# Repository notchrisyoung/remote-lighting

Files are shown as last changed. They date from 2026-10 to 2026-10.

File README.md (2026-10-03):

# Remote Lighting

A wireless dimmer system for LED lighting built from Arduinos and **nRF24L01 2.4 GHz radios**. A wall-mounted button **Controller**, built into a standard single-gang switch plate, sends commands to one or more **Receivers**. Each receiver drives up to three dimmable lighting zones with PWM.

Built in **2018** for under-cabinet kitchen lighting (the photos below are from then), and added to GitHub in April 2021.

| | |
|---|---|
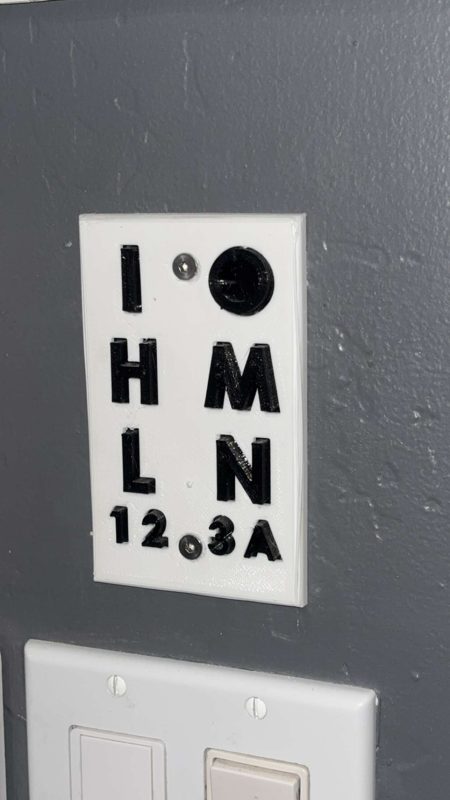
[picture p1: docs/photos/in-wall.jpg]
The in-wall control plate
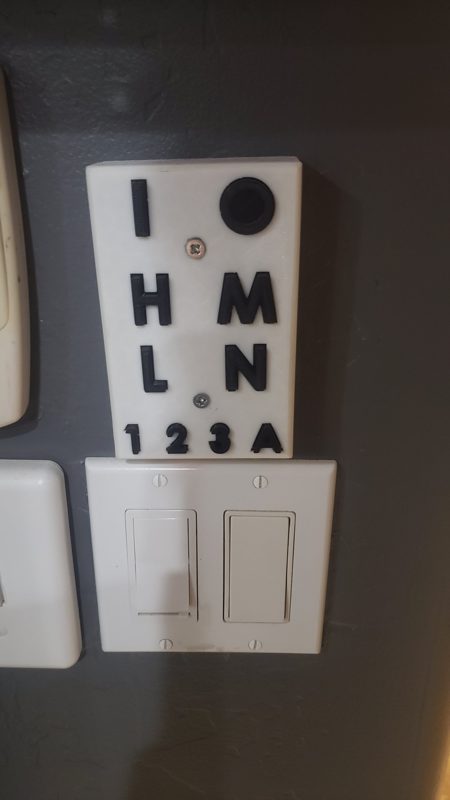
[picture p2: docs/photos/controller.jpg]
The surface-mounted controller
|  |  |
| The in-wall version: the electronics sit inside the wall box, so only the plate shows, like a normal switch plate | The surface-mounted version, with the electronics in a printed box over the wall box |

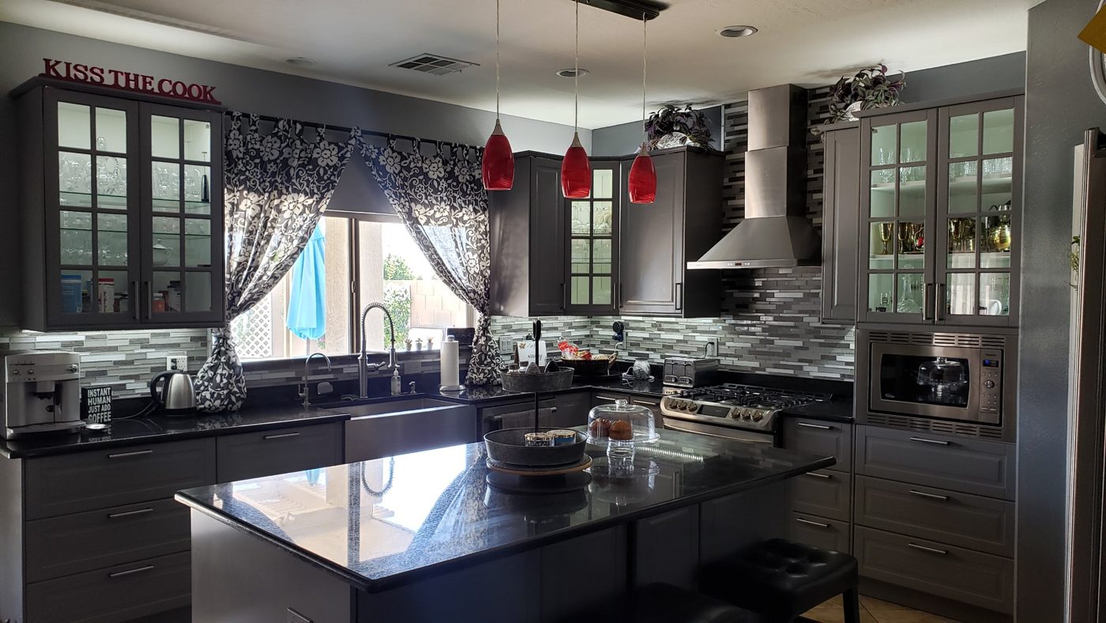
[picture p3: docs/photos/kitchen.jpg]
The kitchen


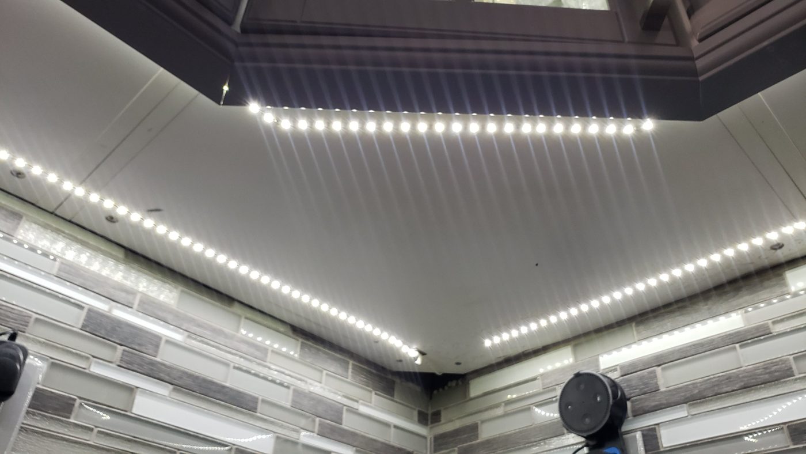
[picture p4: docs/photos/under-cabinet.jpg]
The LED strips under the cabinets


*The kitchen, and the LED strips under the cabinets that the system controls.*

## Features

- **On / Off** for the selected zones. Pressing *On* when already on turns all zones on, and pressing *Off* when already off turns all zones off.
- **Zones 1, 2, 3, or All**
- **Four brightness levels:** High, Medium, Low, and Night light
- Supports up to 4 receivers out of the box (more with a small config change)

## How it works

Every command is a single byte sent over the radio:

| Bits 7-6 | Bit 5 | Bits 4-2 | Bits 1-0 |
|---|---|---|---|
| unused | State: 1 = on, 0 = off | Zone: `001` = 1, `010` = 2, `100` = 3, `111` = all | Brightness: `11` High, `10` Med, `01` Low, `00` Night light |

Receivers map the brightness level to a PWM value (`5, 50, 150, 255`) on each selected zone's pin.

## Hardware

**Controller**
- Arduino (Uno/Nano-class) + nRF24L01 (CE pin 9, CSN pin 10, SPI)
- 10 buttons:

| Button | Pin |
|---|---|
| On | 7 |
| Off | 8 |
| High | A0 |
| Medium | A1 |
| Low | A2 |
| Night light | 6 |
| Zone 1 | 5 |
| Zone 2 | 4 |
| Zone 3 | 3 |
| All zones | 2 |

**Each receiver**
- Arduino + nRF24L01 (CE 9, CSN 10)
- Three MOSFETs on heatsinks driving the LED zones from PWM pins **3, 5 and 6** (zones 1-3)
- 12 V LED strip and a 12 V power supply

## Build

### Controller

| | | |
|---|---|---|
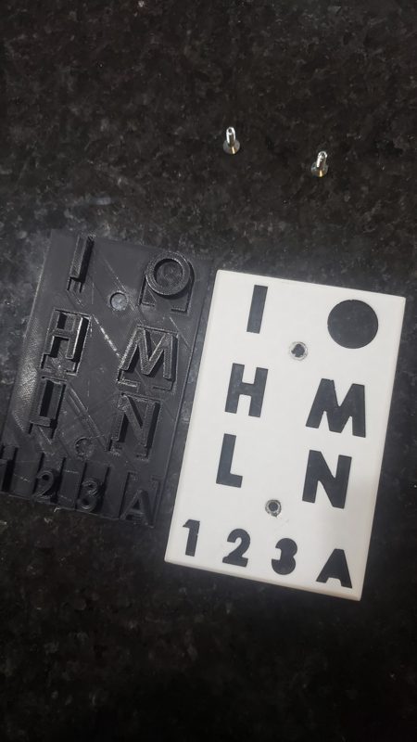
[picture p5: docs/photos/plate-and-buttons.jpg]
Printed wall plate and button sheet
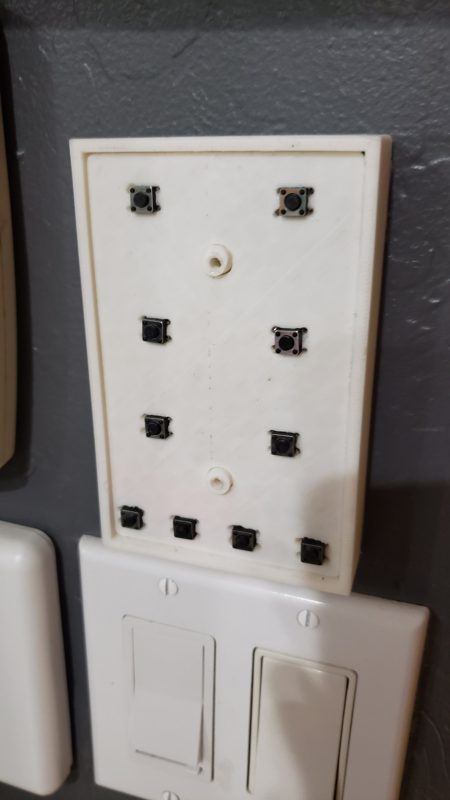
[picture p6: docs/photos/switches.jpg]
The tactile switches under the buttons
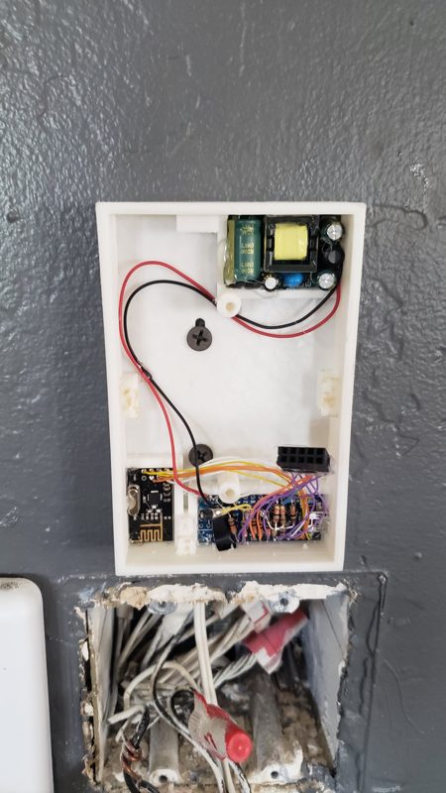
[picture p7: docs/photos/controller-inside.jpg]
Inside the controller
|  |  |  |
| The wall plate and the one-piece letter-button sheet that sits behind it | With the plate off: the 10 tactile switches the letters press | Inside: a small mains-to-DC power module (top), the nRF24L01 radio and the Arduino (bottom) |

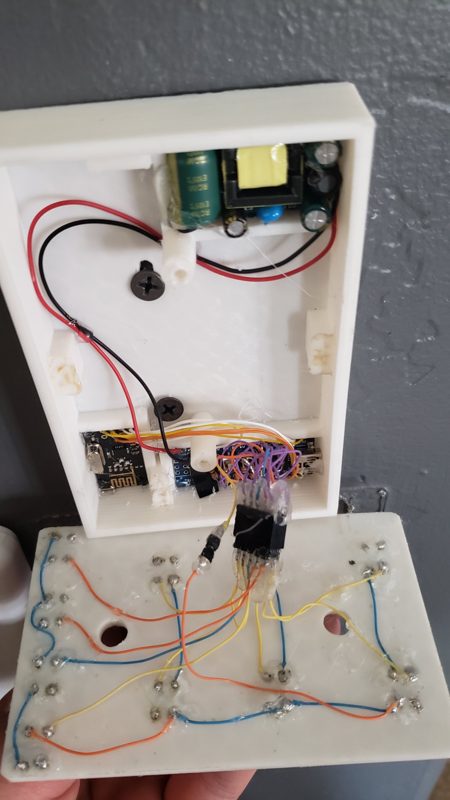
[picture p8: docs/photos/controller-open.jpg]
The controller opened up


The switches are mounted on a printed board and hand-wired to a header that plugs into the Arduino. Behind the controller there's a standard electrical box in the wall, the same kind a normal light switch sits in. The controller mounts over it like a switch plate would, and the box brings mains power to the power module.

> **Mains voltage:** the controller's power module is wired to household mains. Turn the breaker off before working on it, and if you aren't comfortable with mains wiring, power the controller from a USB supply instead.

### Receiver

| | | |
|---|---|---|
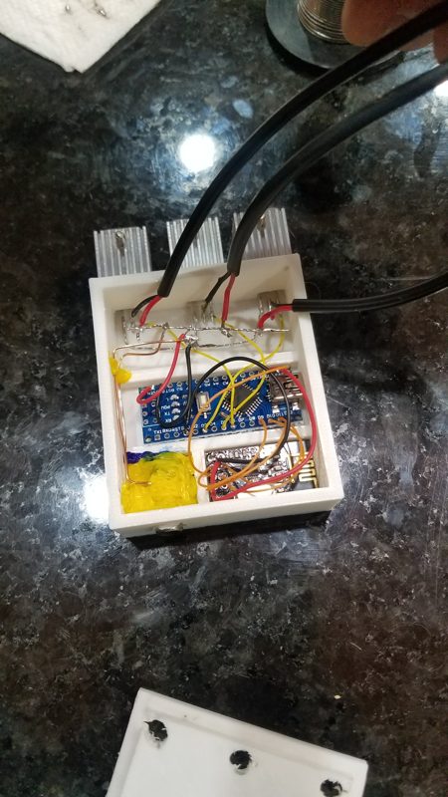
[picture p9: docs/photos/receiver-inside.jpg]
Inside a receiver
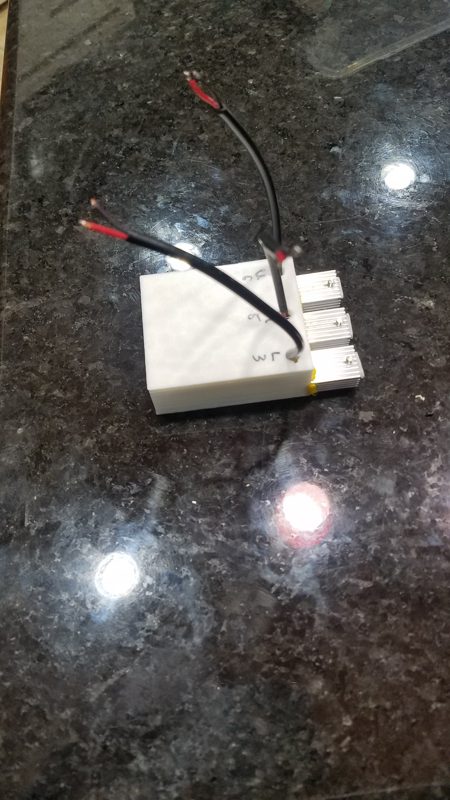
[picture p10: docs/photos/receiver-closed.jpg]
A closed receiver
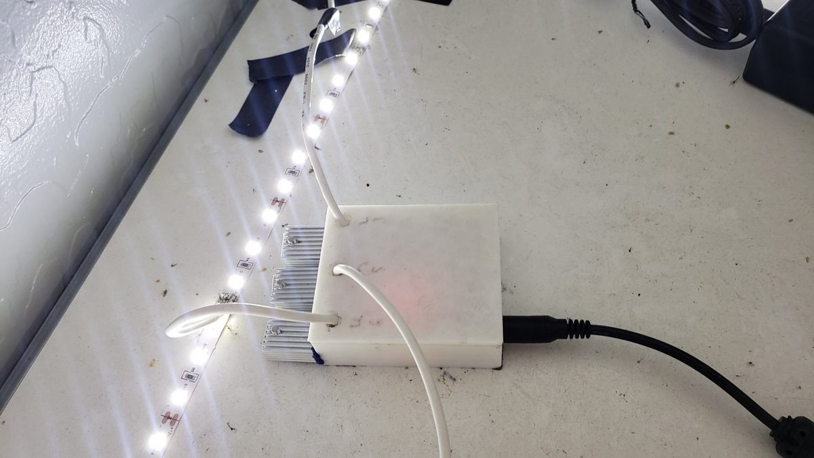
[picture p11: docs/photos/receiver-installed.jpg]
A receiver installed
|  |  |  |
| An Arduino Nano and nRF24L01, with a MOSFET on a heatsink for each of the three zones | Closed up, with the zone outputs labelled | Installed out of sight, driving a 12 V LED strip from a 12 V supply |

## 3D-printed parts

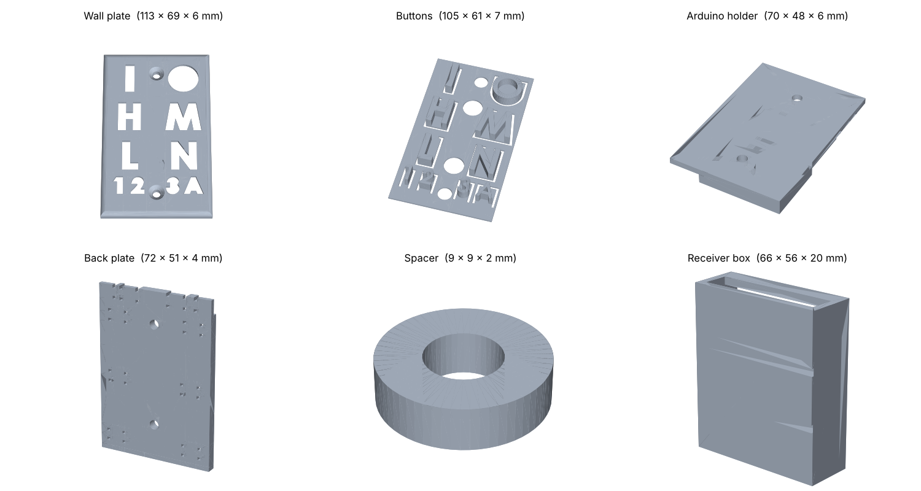
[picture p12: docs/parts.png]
The printed parts


The STL files are in `models/`:

| File | Part |
|---|---|
| `Wall_Plate.STL` | Controller face plate. Standard single-gang switch-plate size (113 × 69 mm), with letter-shaped cut-outs: `I` / `O` (on/off), `H` `M` `L` `N` (high, medium, low, night light) and `1` `2` `3` `A` (zones) |
| `Buttons.STL` | The matching letter-shaped buttons, printed as one sheet that sits behind the wall plate |
| `Arduino_holder.STL` | Mount for the controller's Arduino |
| `Back_Plate.STL` | Controller back plate |
| `Spacer.STL` | Small round spacer (9 mm) |
| `Light_Receiver_-_Box.STL` | Enclosure for a receiver |

GitHub can show the STL files in 3D: open one there to rotate it.

## Setup

1. Install the [RF24 library](https://github.com/nRF24/RF24).
2. `Transmitter.h` holds the radio addresses. **Keep the copies in `Controller/` and `Receiver/` identical.**
3. Flash the **Controller** sketch once.
4. For **each receiver**, set `RECEIVER_NUMBER` in `Receiver/Transmitter.h` to a unique value, then flash it.
5. For more than 4 receivers, add addresses to `recieverAddress[]` and update `RECEIVER_COUNT`.

Both sides use radio channel 8 and low TX power. Change `radio.setChannel()` in both sketches if channel 8 is busy where you are.

## Files

| Path | Purpose |
|---|---|
| `Controller/Controller.ino` | Remote: reads buttons, sends commands |
| `Receiver/Receiver.ino` | Receiver: listens and sets zone brightness |
| `*/Transmitter.h` | Shared radio addresses and receiver count |
| `models/` | 3D-printable parts for the controller and receiver |

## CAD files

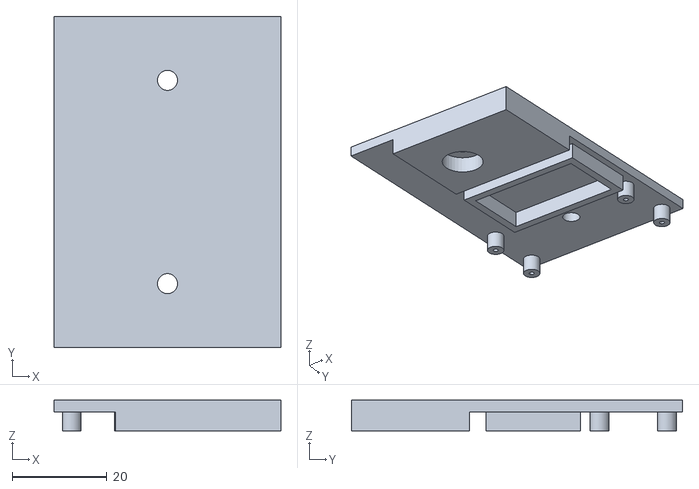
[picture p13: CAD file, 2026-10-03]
models/Arduino_holder.STL
48.0 x 70.0 x 6.50

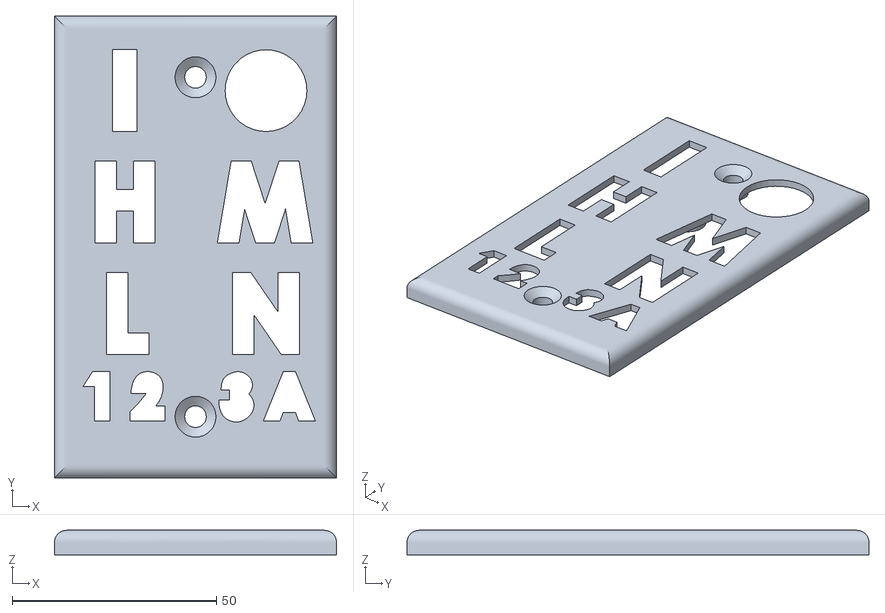
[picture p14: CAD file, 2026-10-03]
models/Wall_Plate.STL
69.0 x 113.0 x 6.00

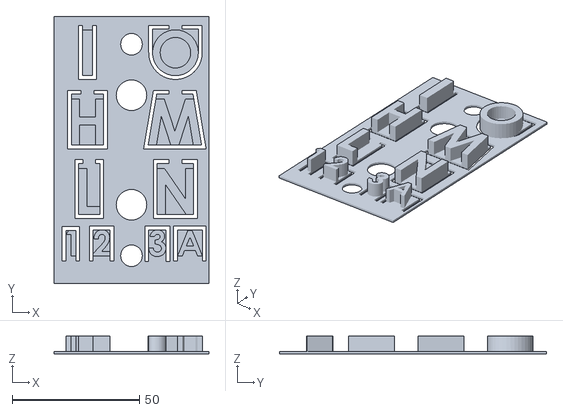
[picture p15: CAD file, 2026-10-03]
models/Buttons.STL
60.8 x 104.8 x 7.00

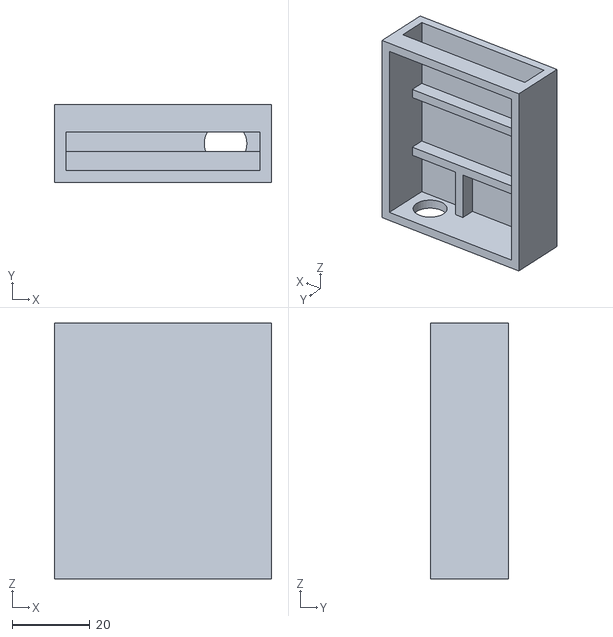
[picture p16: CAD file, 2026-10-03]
models/Light_Receiver_-_Box.STL
56.0 x 20.0 x 66.0

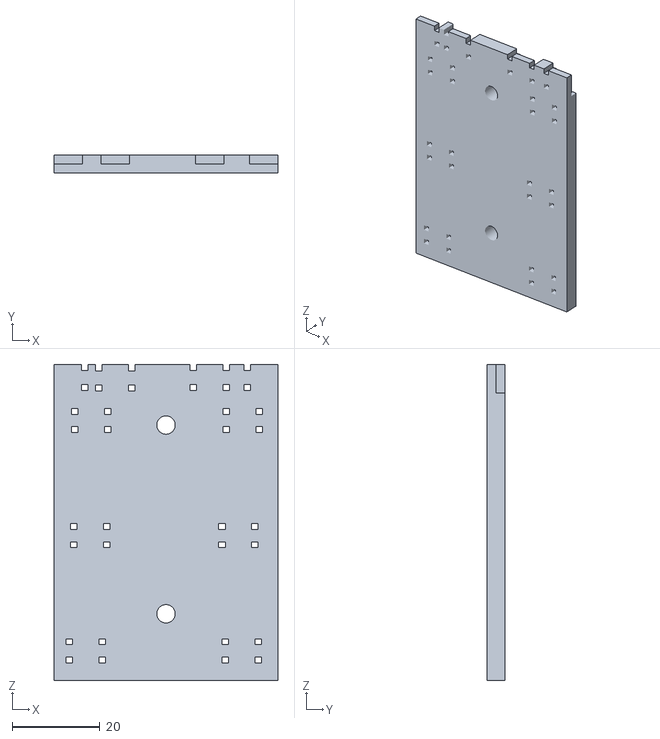
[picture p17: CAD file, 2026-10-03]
models/Back_Plate.STL
51.0 x 4.00 x 72.0

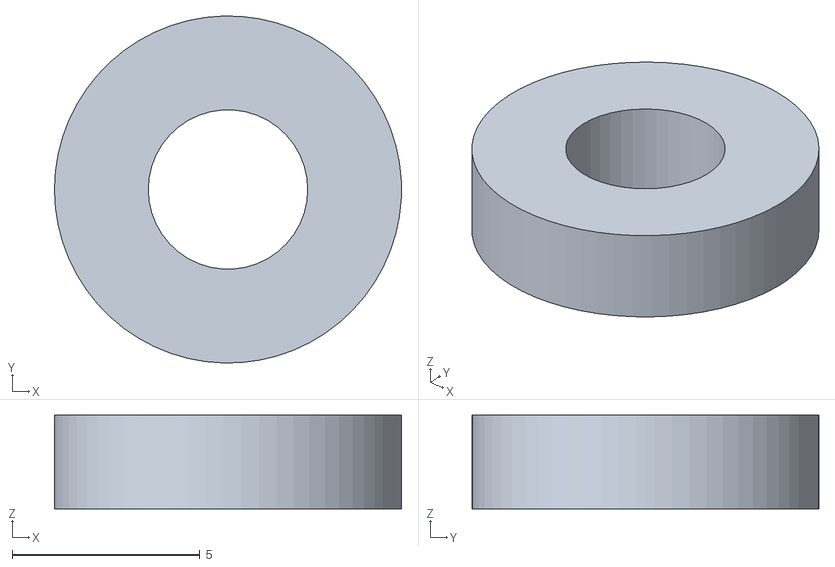
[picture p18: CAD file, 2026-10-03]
models/Spacer.STL
9.25 x 9.25 x 2.50

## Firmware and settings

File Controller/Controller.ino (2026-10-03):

#include <SPI.h>
#include "RF24.h"
#include "printf.h"
#include "Transmitter.h"

// Bit packing chart 8 bits
// | extra | State | Zone  | Brightness |
// |  0 0  | ON:1  | 1:001 |   High:11  |
// |  0 0  | OFF:0 | 2:010 |   Med:10   |
// |  0 0  |  x    | 3:100 |    Lo:01   |
// |  0 0  |  x    | A:111 |    NL:00   |

#define DEBUGGING_ENABLED 0

// Delay value to filter out button noise after press
#define DEBOUNCE_DELAY  50
// Button input pins can be connected to any input pins
#define ON_PIN  7
#define OFF_PIN 8
#define HI_PIN  A0
#define MED_PIN A1
#define LO_PIN  A2
#define NL_PIN  6
#define Z1_PIN  5
#define Z2_PIN  4
#define Z3_PIN  3
#define AZ_PIN  2

const uint8_t button_pins[] ={ON_PIN, OFF_PIN, HI_PIN, MED_PIN, LO_PIN, NL_PIN, Z1_PIN, Z2_PIN, Z3_PIN, AZ_PIN};

// Start state is off with all zones selected on high
uint8_t lightState = 0b00011111;
// Tracks if a zone change is taking place to allow proper function
uint8_t zoneChange = 0;

RF24 radio(9,10);

void setup(void)
{
	Serial.begin(9600);
	printf_begin();
	#if DEBUGGING_ENABLED
		Serial.println("Remote started");
	#endif
	// Setup and configure rf radio
	radio.begin();
	radio.setPALevel(RF24_PA_LOW);
	radio.setChannel(8);
	radio.setRetries(0,15);                 // Smallest time between retries, max no. of retries
	radio.setPayloadSize(1);                // Here we are sending 1-byte
	radio.openReadingPipe(1,controllerAddress);
	// Set every button pin as a plain input (internal pull-up off).
	// The buttons read HIGH when pressed; external resistors pull them low otherwise.
	for (uint8_t i = 0; i < sizeof(button_pins); i++) {
		pinMode(button_pins[i], INPUT);
	}
}

void loop(void)
{
	// Poll each pin to see if the button attached is being pressed
	// On
	if(digitalRead(ON_PIN)){
		#if DEBUGGING_ENABLED
		    Serial.println(F("On"));
		#endif
		if((lightState | 0b00100000) == lightState) lightState |= 0b00111100; // If already on turn all zones on
		else lightState |= 0b00100000; // If not on turn on
		sendChanges();
		while(digitalRead(ON_PIN)){} // Wait untill the button is released by the user
		delay(DEBOUNCE_DELAY); // Delay a small amount of time to allow the voltage to stableize
	}
	// Off
	if(digitalRead(OFF_PIN)){
		#if DEBUGGING_ENABLED
		    Serial.println(F("Off"));
		#endif
		if((lightState & 0b00011111) == lightState){ // If already off turn all zones off
			lightState &= 0b00011111;
			lightState |= 0b00011100;
		}
		else lightState &= 0b00011111; // If on turn off
		sendChanges();
		while(digitalRead(OFF_PIN)){}
		delay(DEBOUNCE_DELAY);
	}
	// High
	if(digitalRead(HI_PIN)){
		#if DEBUGGING_ENABLED
		    Serial.println(F("High"));
		#endif
		if(((lightState | 0b00100011) == lightState) & !zoneChange) lightState = 0b00111111; // If already on high all zones hi
		else lightState |= 0b00100011; // If not set high
		sendChanges();
		while(digitalRead(HI_PIN)){}
		delay(DEBOUNCE_DELAY);
	}
	// Medium
	if(digitalRead(MED_PIN)){
		#if DEBUGGING_ENABLED
		    Serial.println(F("Medium"));
		#endif
		if((((lightState & 0b00111110) | 0b00100010) == lightState) & !zoneChange) lightState = 0b00111110; // If already on mMedium all zones medium
		else lightState = (lightState & 0b00111110) | 0b00100010; // If not set medium
		sendChanges();
		while(digitalRead(MED_PIN)){}
		delay(DEBOUNCE_DELAY);
	}
	if(digitalRead(LO_PIN)){ // Low
		#if DEBUGGING_ENABLED
		    Serial.println(F("Lo"));
		#endif
		if((((lightState & 0b00111101) | 0b00100001) == lightState) & !zoneChange) lightState = 0b00111101; // If already on low all zones low
		else lightState = (lightState & 0b00111101) | 0b00100001;// If not set low
		sendChanges();
		while(digitalRead(LO_PIN)){}
		delay(DEBOUNCE_DELAY);
	}
	if(digitalRead(NL_PIN)){ // Night
		#if DEBUGGING_ENABLED
		    Serial.println(F("Night"));
		#endif
		if((((lightState & 0b00111100) | 0b00100000) == lightState) & !zoneChange) lightState = 0b00111100; // If already on night all zones night
		else lightState = (lightState & 0b00111100) | 0b00100000; // If not set night
		sendChanges();
		while(digitalRead(NL_PIN)){}
		delay(DEBOUNCE_DELAY);
	}
	if(digitalRead(Z1_PIN)){ // Zone 1
		#if DEBUGGING_ENABLED
		    Serial.println(F("Z1"));
		#endif
		zoneChange = 1;
		if((lightState & 0b00011100) == 0b00011100){ // If all zones selected just select one
			lightState &= 0b00100011;
			lightState |= 0b00000100;
		}
		else lightState ^= 0b00000100; // If not toggle
		while(digitalRead(Z1_PIN)){}
		delay(DEBOUNCE_DELAY);
	}
	if(digitalRead(Z2_PIN)){ // Zone 2
		#if DEBUGGING_ENABLED
		    Serial.println(F("Z2"));
		#endif
		zoneChange = 1;
		if((lightState & 0b00011100) == 0b00011100){ // If all zones selected just select one
			lightState &= 0b00100011;
			lightState |= 0b00001000;
		}
		else lightState ^= 0b00001000; // If not toggle
		while(digitalRead(Z2_PIN)){}
		delay(DEBOUNCE_DELAY);
	}
	if(digitalRead(Z3_PIN)){ // Zone 3
		#if DEBUGGING_ENABLED
		    Serial.println(F("Z3"));
		#endif
		zoneChange = 1;
		if((lightState & 0b00011100) == 0b00011100){ // If all zones selected just select one
			lightState &= 0b00100011;
			lightState |= 0b00010000;
		}
		else lightState ^= 0b00010000; // If not toggle
		while(digitalRead(Z3_PIN)){}
		delay(DEBOUNCE_DELAY);
	}
	if(digitalRead(AZ_PIN)){ // All zones
		#if DEBUGGING_ENABLED
		    Serial.println(F("AZ"));
		#endif
		lightState |= 0b00011100; // If not on
		while(digitalRead(AZ_PIN)){}
		delay(DEBOUNCE_DELAY);
	}
}

void sendChanges(void){
	zoneChange = 0;
	for (uint8_t i = 0; i < RECEIVER_COUNT; i++) {
		radio.stopListening();
		radio.openWritingPipe(recieverAddress[i]);
		radio.write(&lightState, 1);
		radio.stopListening();
	}
	#if DEBUGGING_ENABLED
	  Serial.println("Sent");
	#endif
}

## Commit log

2026-10-03 Add the 3D-printed parts for the wall controller and receiver
    Claude-Session: https://claude.ai/code/session_01AUPozFroVL22kzHz3JWSUB
    [Arduino_holder.STL, Back_Plate.STL, Buttons.STL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]
2026-10-03 README: explain the controller mounts over a standard wall box
    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
2026-10-03 Fix the button setup loop in the controller and drop the known-issues note
    The loop was written for(i = 0; i++; i < 9), so it never ran. It now sets
    all 10 button pins to INPUT. The comment is corrected too: the buttons read
    HIGH when pressed, with external pull-down resistors.
    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
    [Controller.ino]
2026-10-03 README: show the in-wall control plate
    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
